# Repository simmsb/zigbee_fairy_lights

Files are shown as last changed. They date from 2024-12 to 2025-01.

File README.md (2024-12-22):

# Esp32 battery powered Zigbee fairy lights

A little thing I threw together this christmas.

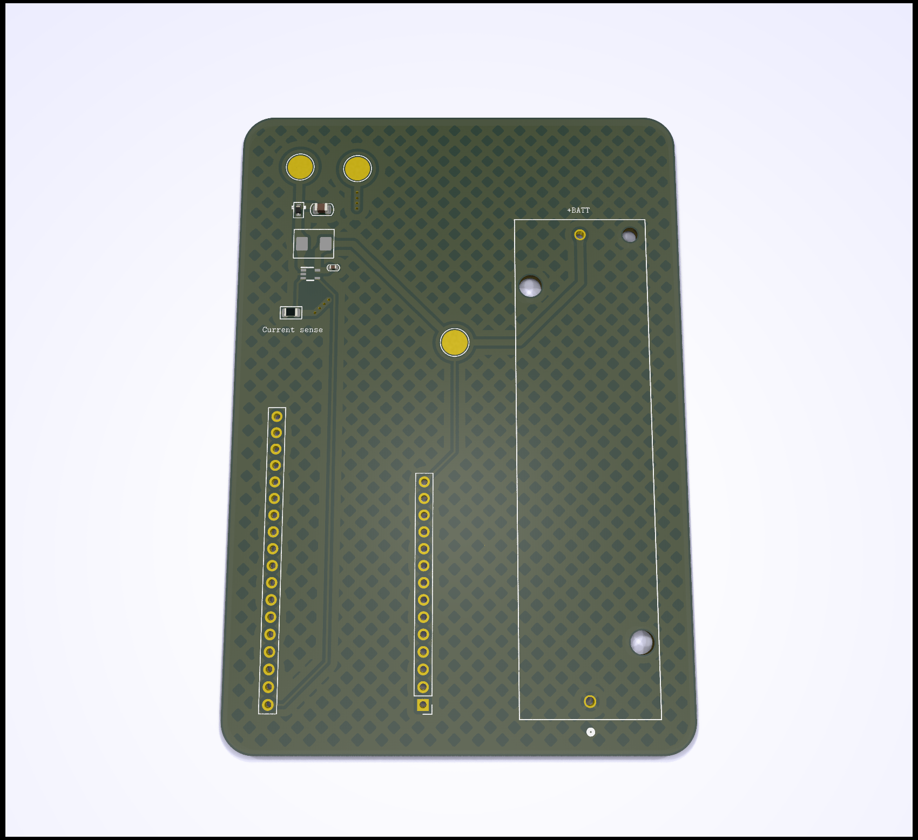
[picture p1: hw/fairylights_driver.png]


It uses a DFRobot firebeetle2 esp32c6 as a zigbee end device, which is then used
to manage the output of a LED driver.

This is then used to power some outdoor fairy lights.

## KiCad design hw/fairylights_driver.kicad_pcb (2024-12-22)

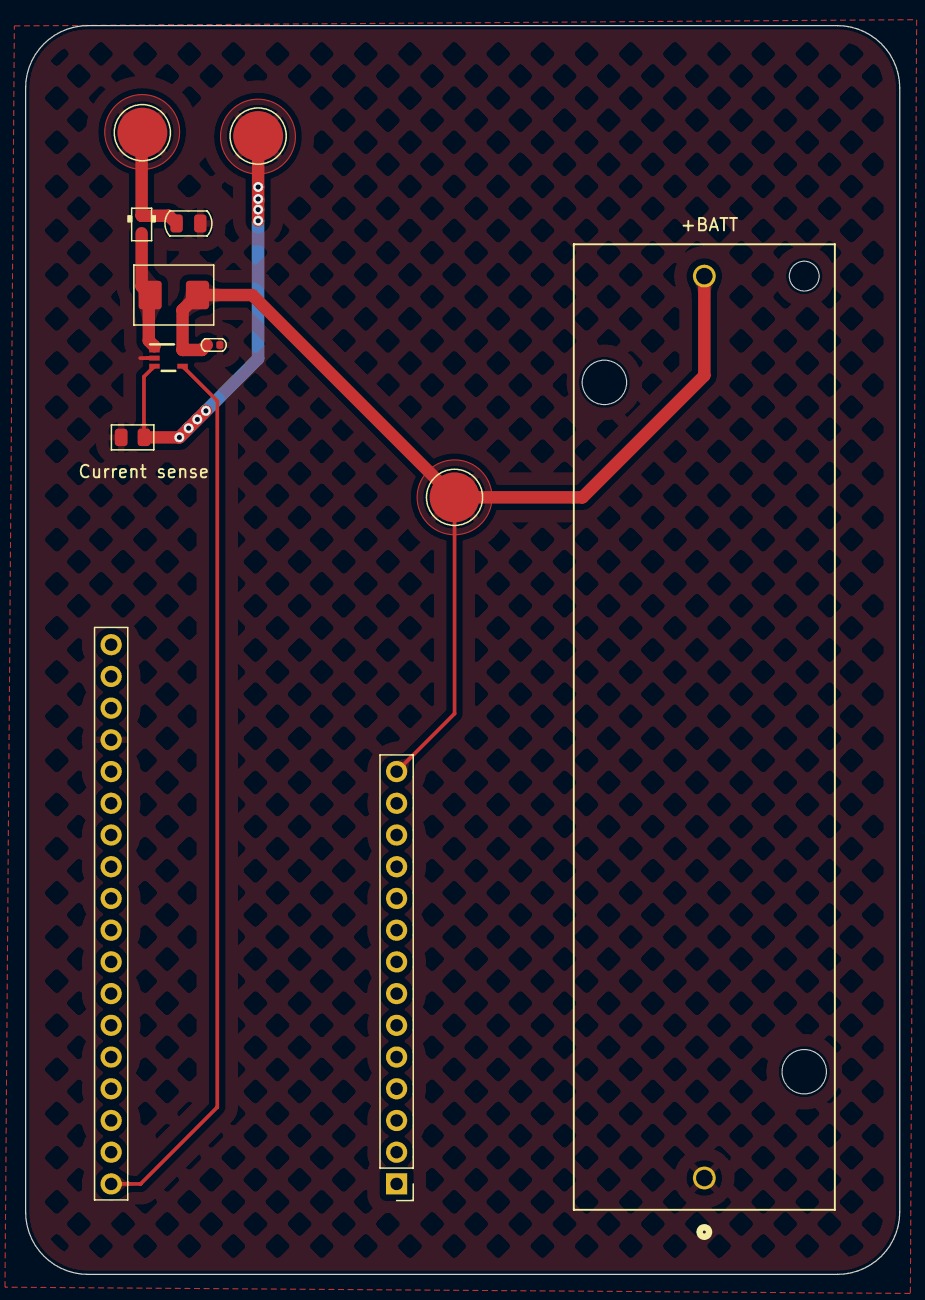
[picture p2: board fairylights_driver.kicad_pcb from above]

Board: 2 copper layers, 70.0 x 100.0 mm, 11 parts (0 on the bottom side), 6 nets.

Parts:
B1: 1043P; BATT_1043P_KEY
C2: 4.7uF; C_0402_1005Metric
C3: 1uF; C_0805_2012Metric
D1: D_Schottky_Generic; D_SOD-523
J1: +LED; TestPoint_Pad_D4.0mm
J2: -LED; TestPoint_Pad_D4.0mm
J3: VIN; TestPoint_Pad_D4.0mm
L1: IHLP1616BZER4R7M11; L_Vishay_IHLP-1616
R2: 5.1; R_0805_2012Metric
U1: firebeetle2
U2: TPS61169DCKR; DCK0005A_N

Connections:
/ctrl: U1.15 (PA17), U2.4 (CTRL)
/vin: B1.2, C2.1, J3.1, L1.1, U1.14 (VIN), U2.5 (VIN)
GND: B1.1, C2.2, C3.2, R2.2, U1.29 (GND), U2.2 (GND)
unnamed: D1.2 (A), L1.2, U2.1 (SW)
unnamed: C3.1, D1.1 (K), J1.1
unnamed: J2.1, R2.1, U2.3 (FB)

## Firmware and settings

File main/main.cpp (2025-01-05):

#include <cmath>
#include <cstdint>

#include "esp_log.h"
#include "esp_zigbee_type.h"
#include "freertos/projdefs.h"
#include "hal/gpio_types.h"
#include "hal/ledc_types.h"
#include "nvs_flash.h"
#include "portmacro.h"
#include "soc/gpio_num.h"
#include "utils/adc_sensor.h"
#include "utils/binary_output.h"
#include "utils/gpio.h"
#include "utils/gpio_binary_output.h"
#include "utils/isr_gpio.h"
#include "utils/ledc.h"
#include "zcl/esp_zigbee_zcl_analog_output.h"
#include "zcl/esp_zigbee_zcl_common.h"
#include "zigbee/zigbee.h"
#include "zigbee/zigbee_attribute.h"
#include "zigbee/zigbee_trigger.h"
#include "opt/optional.hpp"

static const char *TAG = "LIGHTS";

gpio::GPIOBinaryOutput *statusLed;

QueueHandle_t ledqueue;

struct LedState {
  bool on;
  uint8_t level;
};

struct SetLedState {
  union {
    bool on;
    uint8_t level;
  } u;
  bool isOnSet;
};

class OnOffHandler : public zigbee::ZigBeeOnValueTrigger<bool> {
  using zigbee::ZigBeeOnValueTrigger<bool>::ZigBeeOnValueTrigger;

  void trigger(bool x) {
    ESP_LOGI(TAG, "on off triggered: %d", x);
    auto msg = SetLedState{.u =
                               {
                                   .on = x,
                               },
                           .isOnSet = true};
    statusLed->turn_on();
    xQueueSend(ledqueue, &msg, portMAX_DELAY);
    statusLed->turn_off();
  }
};

class SetLevelHandler : public zigbee::ZigBeeOnValueTrigger<uint8_t> {
  using zigbee::ZigBeeOnValueTrigger<uint8_t>::ZigBeeOnValueTrigger;

  void trigger(uint8_t x) {
    ESP_LOGI(TAG, "set level triggered: %d", x);
    auto msg = SetLedState{.u =
                               {
                                   .level = x,
                               },
                           .isOnSet = false};
    statusLed->turn_on();
    xQueueSend(ledqueue, &msg, portMAX_DELAY);
    statusLed->turn_off();
  }
};

ledc::LEDCOutput *ledOutput;

void ledUpdateTask(void *arg) {
  uint8_t level = 0;
  uint8_t savedLevel = 0;

  tl::optional<zigbee::ZigbeeWakelock> wakelock = tl::nullopt;

  for (;;) {
    SetLedState newStateSet;
    if (xQueueReceive(ledqueue, &newStateSet, portMAX_DELAY) != pdPASS) {
      continue;
    }

    auto desiredLevel = level;

    if (newStateSet.isOnSet) {
      if (newStateSet.u.on)
        desiredLevel = savedLevel;
      else {
        savedLevel = level;
        desiredLevel = 0;
      }
    } else {
      desiredLevel = newStateSet.u.level;
    }

    if (level > 0 || desiredLevel > 0) {
      wakelock = zigbee::inhibit_sleep();
      // need to run setup again after sleeping?
      ledOutput->setup();
    }

    int direction = (level < desiredLevel) ? 1 : -1;
    for (size_t i = level, iEnd = desiredLevel + direction; i != iEnd;
         i += direction) {
      auto preGamma = (float)i / 255.0;
      auto gammaCorrected = std::pow(preGamma, 2.8);
      ledOutput->set_level(gammaCorrected);

      vTaskDelay(pdMS_TO_TICKS(16));
    }

    level = desiredLevel;

    if (level == 0) {
      wakelock.reset();
    }
  }
}

float interp_linear(float value, std::vector<std::array<float, 3>> filter) {
  for (std::array<float, 3> f : filter) {
    if (!std::isfinite(f[2]) || value < f[2])
      return (value * f[0]) + f[1];
  }
  return NAN;
}

zigbee::ZigBeeAttribute *power_cfg_battery_remaining;
zigbee::ZigBeeAttribute *adc_raw;

void batteryUpdateTask(void *arg) {
  std::vector<std::array<float, 3>> filt = {
      {0.30303030303030304f, 0.0f, 3.3f},
      {99.99999999999966f, -328.99999999999886f, 3.39f},
      {111.11111111111114f, -366.6666666666668f, 3.75f},
      {111.11111111111101f, -366.6666666666663f, 4.11f},
      {111.11111111111128f, -366.6666666666674f, NAN}};

  for (;;) {
    auto wakelock = zigbee::inhibit_sleep();
    statusLed->turn_on();
    esp32::ESP32InternalGPIOPin batterypin {};
    batterypin.set_pin(GPIO_NUM_0);
    batterypin.set_inverted(false);
    batterypin.set_drive_strength(GPIO_DRIVE_CAP_2);
    batterypin.set_flags(gpio::FLAG_INPUT);
    batterypin.setup();
    adc::ADCSensor batteryLevel {};
    batteryLevel.set_pin(&batterypin);
    batteryLevel.set_output_raw(false);
    batteryLevel.set_sample_count(10);
    batteryLevel.set_attenuation(adc::ADC_ATTEN_DB_12_COMPAT);
    batteryLevel.set_channel1(::ADC1_CHANNEL_0);
    batteryLevel.setup();

    // 1/2 potential divider on the battery input
    float s = batteryLevel.sample() * 2.0;
    auto r = interp_linear(s, filt);

    if (r > 100.0) {
      r = 100.0;
    } else if (r < 0.0) {
      r = 0.0;
    }

    uint8_t value = (uint8_t)(r * (200.0 / 100.0));

    ESP_LOGI(TAG, "Ticking adc, got: %d (raw %f)", value, s);

    power_cfg_battery_remaining->set_attr(&value);
    adc_raw->set_attr(&s);


    statusLed->turn_off();

    wakelock.reset();

    vTaskDelay(pdMS_TO_TICKS(1000 * 60));
  }
}

extern "C" void app_main(void) {
  ESP_LOGI(TAG, "hello world");
  ESP_ERROR_CHECK(nvs_flash_init());

  auto ledpin = new esp32::ESP32InternalGPIOPin();
  ledpin->set_pin(GPIO_NUM_15);
  ledpin->set_inverted(false);
  ledpin->set_drive_strength(GPIO_DRIVE_CAP_2);
  ledpin->set_flags(gpio::FLAG_OUTPUT);
  ledpin->setup();
  statusLed = new gpio::GPIOBinaryOutput();
  statusLed->set_pin(ledpin);
  statusLed->setup();

  ledqueue = xQueueCreate(1, sizeof(LedState));

  auto zb = new zigbee::ZigBeeComponent();
  zb->set_basic_cluster("toad-lights", "ben", "2024", 3, 0, 0, 0, "", 0);
  zb->create_default_cluster(1, ESP_ZB_HA_DIMMABLE_LIGHT_DEVICE_ID);
  zb->add_cluster(1, ESP_ZB_ZCL_CLUSTER_ID_BASIC,
                  ESP_ZB_ZCL_CLUSTER_SERVER_ROLE);
  zb->add_cluster(1, ESP_ZB_ZCL_CLUSTER_ID_ON_OFF,
                  ESP_ZB_ZCL_CLUSTER_SERVER_ROLE);

  auto on_off_attr = new zigbee::ZigBeeAttribute(
      zb, 1, ::ESP_ZB_ZCL_CLUSTER_ID_ON_OFF, ::ESP_ZB_ZCL_CLUSTER_SERVER_ROLE,
      0, ::ESP_ZB_ZCL_ATTR_TYPE_BOOL);
  on_off_attr->add_attr(0, 0);

  auto mainoutputpin = new esp32::ESP32InternalGPIOPin();
  mainoutputpin->set_pin(GPIO_NUM_17);
  mainoutputpin->set_inverted(false);
  mainoutputpin->set_drive_strength(GPIO_DRIVE_CAP_2);
  mainoutputpin->set_flags(gpio::FLAG_OUTPUT);
  mainoutputpin->setup();
  auto mainoutput = new ledc::LEDCOutput(mainoutputpin);
  mainoutput->set_frequency(10000.0);
  mainoutput->set_zero_means_zero(false);
  mainoutput->setup();
  mainoutput->set_state(false);

  ledOutput = mainoutput;

  xTaskCreate(ledUpdateTask, "ledUpdate", 2048, NULL, 10, NULL);


  (new OnOffHandler(on_off_attr))->setup();
  // on_off_attr->add_on_value_callback([=](esp_zb_zcl_attr_t x) {
  // });

  zb->add_cluster(1, ::ESP_ZB_ZCL_CLUSTER_ID_LEVEL_CONTROL,
                  ::ESP_ZB_ZCL_CLUSTER_SERVER_ROLE);
  auto level_attr = new zigbee::ZigBeeAttribute(
      zb, 1, ::ESP_ZB_ZCL_CLUSTER_ID_LEVEL_CONTROL,
      ::ESP_ZB_ZCL_CLUSTER_SERVER_ROLE, 0, ::ESP_ZB_ZCL_ATTR_TYPE_U8);
  level_attr->add_attr(0, 0);

  (new SetLevelHandler(level_attr))->setup();

  zb->add_cluster(1, ::ESP_ZB_ZCL_CLUSTER_ID_POWER_CONFIG,
                  ::ESP_ZB_ZCL_CLUSTER_SERVER_ROLE);
  power_cfg_battery_remaining = new zigbee::ZigBeeAttribute(
      zb, 1, ::ESP_ZB_ZCL_CLUSTER_ID_POWER_CONFIG,
      ::ESP_ZB_ZCL_CLUSTER_SERVER_ROLE,
      ZB_ZCL_ATTR_POWER_CONFIG_BATTERY_PERCENTAGE_REMAINING_ID,
      ::ESP_ZB_ZCL_ATTR_TYPE_U8);
  power_cfg_battery_remaining->add_attr(0, 0);
  power_cfg_battery_remaining->set_report();

  auto power_cfg_battery_size = new zigbee::ZigBeeAttribute(
      zb, 1, ::ESP_ZB_ZCL_CLUSTER_ID_POWER_CONFIG,
      ::ESP_ZB_ZCL_CLUSTER_SERVER_ROLE,
      ZB_ZCL_ATTR_POWER_CONFIG_BATTERY_SIZE_ID, ::ESP_ZB_ZCL_ATTR_TYPE_U8);
  power_cfg_battery_size->add_attr(0,
                                   ZB_ZCL_POWER_CONFIG_BATTERY_SIZE_BUILT_IN);

  zb->add_cluster(1, ::ESP_ZB_ZCL_CLUSTER_ID_ANALOG_OUTPUT,
                  ::ESP_ZB_ZCL_CLUSTER_SERVER_ROLE);
  adc_raw = new zigbee::ZigBeeAttribute(
      zb, 1, ::ESP_ZB_ZCL_CLUSTER_ID_ANALOG_OUTPUT,
      ::ESP_ZB_ZCL_CLUSTER_SERVER_ROLE,
      ESP_ZB_ZCL_ATTR_ANALOG_OUTPUT_PRESENT_VALUE_ID,
      ::ESP_ZB_ZCL_ATTR_TYPE_SINGLE);
  adc_raw->add_attr(0, (float)0.0);
  adc_raw->set_report();

  xTaskCreate(batteryUpdateTask, "batteryUpdate", 4096, NULL, 10, NULL);

  zb->setup();
}

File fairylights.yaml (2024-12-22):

esphome:
  name: toad-lights
  comment: Toad lights

external_components:
  # - source: github://luar123/zigbee_esphome
  #   components: [zigbee]
  
  - source: github://simmsb/zigbee_esphome
    components: [zigbee]

  - source: github://pr#7942
    refresh: 1h
    components:
      - adc

esp32:
  board: esp32-c6-devkitc-1
  variant: esp32c6
  flash_size: 4MB
  partitions: partitions_zb.csv
  framework:
    type: esp-idf
    # version: latest
    # sdkconfig_options:
    #   CONFIG_ESPTOOLPY_FLASHSIZE_4MB: y

    version: '5.3.1'
    platform_version: '6.9.0'
    # source: |-
    #   https://github.com/tasmota/esp-idf/releases/download/v5.1.3.240313/esp-idf-v5.1.3.zip
    sdkconfig_options: 
      CONFIG_ZB_ENABLED: y
      CONFIG_ZB_ZED: y
      CONFIG_ZB_RADIO_NATIVE: y
      ZB_ED_ROLE: y

# Enable logging
logger:
  hardware_uart: USB_SERIAL_JTAG
#   hardware_uart: UART0

sensor:
  - platform: internal_temperature
    name: "Internal Temperature"
    id: "temp"
    filters:
      - delta: 0.1

  - platform: adc
    id: battery_percentage
    name: "Battery percentage"
    pin: 0
    accuracy_decimals: 2
    update_interval: 60s
    attenuation: 12dB
    samples: 10
    filters:
      - multiply: 2.0  # The voltage divider requires us to multiply by 2
      - calibrate_linear:
         method: exact
         datapoints:
          - 0.00 -> 0.0
          - 3.30 -> 1.0
          - 3.39 -> 10.0
          - 3.75 -> 50.0
          - 4.11 -> 90.0
          - 4.20 -> 100.0
      - lambda: |-
          if (x <= 100) {
            return x;
          } else {
            return 100;
          }
          if (x <0) {
            return 0;
          }
zigbee:
  id: "zb"
  endpoints:
    - num: 1
      device_type: DIMMABLE_LIGHT
      clusters:
        - id: ON_OFF
          attributes:
            - attribute_id: 0
              type: bool
              on_value:
                then:
                  - light.control:
                      id: light_1
                      state: !lambda "return (bool)x;"
                  - light.control:
                      id: light_status
                      state: !lambda "return (bool)x;"
        - id: LEVEL_CONTROL
          attributes:
            - attribute_id: 0
              type: U8
              on_value:
                then:
                  - light.control:
                      id: light_1
                      brightness: !lambda "return ((float)x)/255;"
        - id: TEMP_MEASUREMENT
          attributes:
            - attribute_id: 0x0
              type: S16
              report: true
              value: 100
              device: temp
              scale: 100
        - id: POWER_CONFIG
          attributes:
            # https://github.com/espressif/esp-zigbee-sdk/blob/a943a91/components/esp-zigbee-lib/include/zcl/esp_zigbee_zcl_power_config.h
            - attribute_id: 0x0021 # ESP_ZB_ZCL_ATTR_POWER_CONFIG_BATTERY_PERCENTAGE_REMAINING_ID
              type: u8
              report: true
              device: battery_percentage
              lambda: !lambda "return x * (200.0 / 100.0);"
            - attribute_id: 0x0031 # ESP_ZB_ZCL_ATTR_POWER_CONFIG_BATTERY_SIZE_ID
              type: u8
              value: 0x1 # ESP_ZB_ZCL_POWER_CONFIG_BATTERY_SIZE_BUILT_IN
              
  on_join:
    then:
      - logger.log: "Joined network"

light:
  - platform: binary
    output: light_status_gpio
    id: light_status

  - platform: monochromatic
    output: boost_on
    id: light_1
    on_turn_on:
      - output.turn_on:
          id: fet_on
    on_turn_off:
      - output.turn_off:
          id: fet_on

output:
  - platform: gpio
    pin: 15
    id: light_status_gpio
  - platform: gpio
    pin: 16
    id: fet_on
  - platform: ledc
    pin: 17
    id: boost_on 
    frequency: "10khz"
    max_power: "45%"

binary_sensor:
  - platform: gpio
    pin:
      number: 9
      mode:
        input: true
        pullup: true
      inverted: true
    id: button_1
    on_press:
      then:
        - zigbee.report: zb
    on_click:
      min_length: 5s
      max_length: 20s
      then:
        - zigbee.reset: zb

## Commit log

2024-12-24 fix adc: reinitialise it each time
    [adc_sensor.cpp, main.cpp]
2025-01-05 Actually fix adc after sleep
    [adc_sensor.cpp, adc_sensor.h, main.cpp]
